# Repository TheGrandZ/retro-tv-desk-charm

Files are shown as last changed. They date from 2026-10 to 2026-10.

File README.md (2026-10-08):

# Retro TV Desk Charm

A tiny 3D printed retro TV that loops short video clips on your desk. You send clips to it straight from your phone over WiFi. No app, no computer, no cables after the first setup.

> **Status:** working prototype. Plays clips, takes uploads from a phone, housing fits.
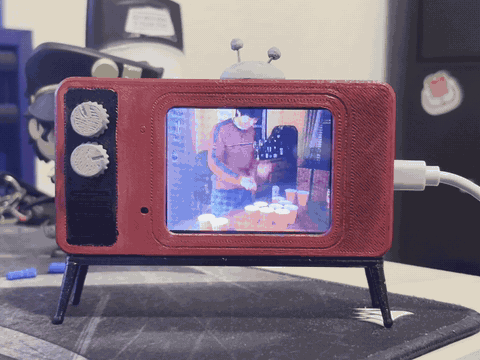
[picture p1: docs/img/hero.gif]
Retro TV playing a clip


## What it does

- **Loops video clips** from a microSD card on a 2.8 inch screen (320 x 240).
- **Phone upload over WiFi.** The TV serves its own web page. Pick a video, choose the start point and length, tap send.
- **Converts in the browser.** The phone turns the video into the format the TV needs, so the TV never has to do heavy work.
- **Clip manager.** Play or delete any clip from the same page.
- **Brightness control** that the TV remembers when unplugged.
- **Turnable magnetic knobs** and a filament-rod antenna, because it is a TV. (Can also use thumbtacks metal)

## Parts

| Part | Notes |
|---|---|
| ESP32-2432S028R ("Cheap Yellow Display") | 2.8 inch ILI9341 touchscreen board. Mine is the two-port version (micro-USB and USB-C). |
| microSD card | Must be **FAT32**. exFAT cards are not read. |
| 4 x disc magnets, 5 x 2 mm | One in each knob, one in each socket. |
| 2 x M3 x 6 mm hex screws | Hold the board in the body. |
| 2 x M3 nuts | Used as spacers under the screw heads. The 6 mm screws were too long for the inserts on their own. |
| M3 brass threaded inserts, about 3 mm long | Set into the body so the screws bite into metal, not plastic. <!-- TODO: confirm exact insert size from the bag --> |
| 1.75 mm filament offcuts | Used as dowel pins and as the antenna rods. |
| USB-C cable | Power only. |
| PLA | Printed on an Ender 3 Pro. |

## How it works

```mermaid
flowchart LR
    A[Phone browser] -->|1. pick video, choose start and length| B[Page draws each frame to a canvas]
    B -->|2. saves frames as JPEGs, 320 x 240| C[One .mjpeg file]
    C -->|3. WiFi upload| D[ESP32 web server]
    D -->|4. writes to| E[(microSD /mjpeg)]
    E -->|5. read frame| F[JPEG decoder]
    F -->|6. draw| G[2.8 inch screen]
```

**MJPEG in one line:** a video stored as a stack of ordinary JPEG pictures, one per frame. It is a bigger file than a normal video, but it is simple enough for a small chip to decode.

### Firmware

- Arduino sketch for the ESP32 (Arduino core 3.x), about 830 lines.
- Starts its own WiFi network (`RetroTV`), or joins home WiFi if the SD card has a `wifi.txt` file. On home WiFi the page is at `http://retrotv.local`.
- Web server routes: `/` (the page), `/list`, `/play`, `/delete`, `/upload`, `/light`.
- **Uploads never interrupt a frame.** A new clip is written to a temp file, then swapped in between clips.
- **Frame skipping.** If the board cannot keep up, it drops frames instead of slowing down, so a 5 second clip still takes 5 seconds.
- **Oversized frames are handled safely.** A frame larger than the buffer stops that clip instead of overflowing memory.
- Clip speed is stored in the file name, for example `beach.f12.mjpeg` plays at 12 frames a second.

### Phone page

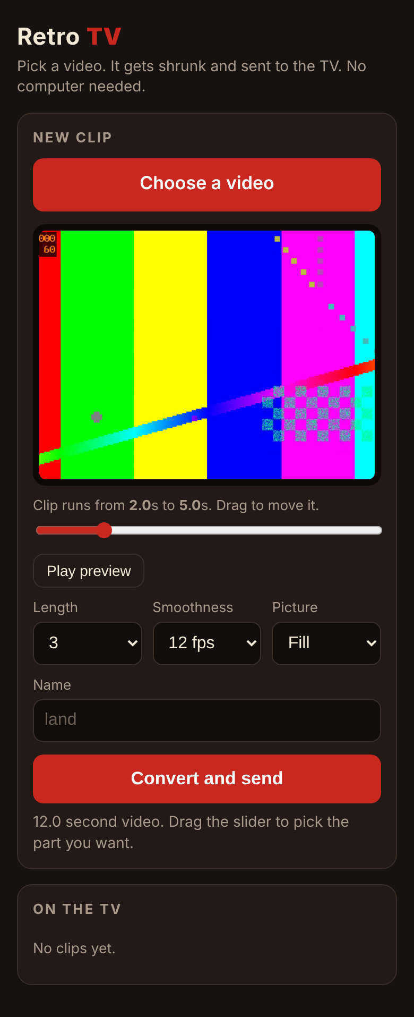
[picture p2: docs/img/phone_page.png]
The upload page on a phone


- One HTML file (about 14 KB) stored inside the firmware.
- Live preview while you drag the start slider, plus a "Play preview" button.
- Fast conversion: plays the video at 2x and grabs frames as they appear (`requestVideoFrameCallback`). Older browsers fall back to a slower frame-by-frame method.
- Frames that come out too big are re-compressed before sending.

### Housing

- Modelled in code (Python with `trimesh` and `manifold3d`), not in a CAD program. Every dimension is a named number in one script, so a fit problem is a one line change and a re-export.
- Built around an existing CYD front case so the board seat was already proven.
- Printed parts: body, stand, 2 knobs, antenna base, 2 antenna tips. <!-- TODO: add the rear cap back to this list if you kept it -->
- **No printed back cover.** The board is screwed straight into the body with M3 brass threaded inserts and hex screws, so it can come out and go back in without wearing out the plastic.
- Small fit-test pieces (USB and SD end, one knob socket) so I could check fit with a short print instead of reprinting the whole body.

## Design log

Eight housing revisions. Each one came from a real print and a real problem.

| Problem found on the print | Fix |
|---|---|
| Shell blocked the USB-C port (I had only opened the micro-USB side) | Opened the USB-C side, then narrowed it to a port-only window |
| Rear cap would not sit flush and warped | Redesigned as a thicker cap with a lip and pegs |
| SD card sat too deep to pull out | Added a finger scoop and a guided slot |
| Unused connectors and bare board visible | Covered them, added a faceplate around USB-C |
| Screen sat too far behind the front (2.6 mm) | Removed an extra lip, now 1.0 mm |
| Knob panel printed as loose strands | A wide recess on the bed side was printing in mid-air. Replaced with a flat panel and a thin outline groove |
| Whole body was exported upside down | Re-exported front face down |
| Printed back cover did not hold tight | Dropped it. M3 brass threaded inserts in the body, board held with M3 hex screws |

**Lessons I would reuse:**

1. **Print a small test piece first.** Most fit bugs showed up on a small test piece, not the full body.
2. **Nothing wide and hollow on the bed-side face.** It has to bridge in mid-air.
3. **Check orientation in the slicer every time.** One wrong flip hid behind several "print quality" problems.

## Performance

Measured on the real board, from the serial log:

| Clip target | What the board managed |
|---|---|
| 15 fps | 11.8 to 11.9 fps |

So the practical ceiling is **about 12 fps at 320 x 240**. The page defaults to 12 fps for that reason, and frame skipping covers the 15 fps option.

Likely bottlenecks, not yet measured separately: reading from the SD card, JPEG decoding, and pushing pixels over SPI. The firmware prints a per-frame timing breakdown to help find out which.

## Testing

- **Phone page:** automated browser tests (Playwright) against a mock TV server. Covers preview scrubbing, landscape and portrait video, fill and fit, name cleaning, oversized frames, and the older-browser path.
- **Firmware logic:** the real sketch compiled on a PC with stand-in hardware headers and the real JPEG decoder, run under AddressSanitizer. 43 checks across four boot scenarios (own network, empty card, home WiFi, home WiFi unreachable). This caught two memory bugs in the original MJPEG reader.
- **Real hardware:** playback and WiFi upload confirmed on the board. The brightness slider is checked in simulation only so far.

Run them yourself:

```bash
tests/page/run_tests.sh   # phone page, needs Python and Playwright
tests/sim/run_sim.sh      # firmware logic, needs g++ and git
```

## Limits

- No sound.
- Up to 40 clips, up to 30 seconds each.
- About 12 fps.
- FAT32 cards only.
- WiFi networks that need a username (like eduroam) do not work.
- The stand's second pin hole misses the frame, so it uses one pin plus glue.

## What I would do next

- Find the real fps bottleneck with the timing report, then try lighter JPEGs or splitting decode and draw across the two CPU cores.
- An ESP32-S3 board for 24 fps and sound.
- Battery and charging in the empty space at the back.
- Fix the stand pin hole.

## What is in this repo

| Folder | What |
|---|---|
| `firmware/RetroTV_Player/` | The Arduino sketch. `webpage.h` is the phone page stored as a string. |
| `firmware/page/` | The phone page source (`index.html`). |
| `case/` | The Python script that builds the housing, and the printable STL files. |
| `tests/` | Browser tests for the page and the PC simulation of the firmware. |
| `docs/img/` | Pictures. |

## Build it

1. **Flash:** open `firmware/RetroTV_Player/RetroTV_Player.ino` in Arduino IDE, board "ESP32 Dev Module", install the libraries *GFX Library for Arduino* and *JPEGDEC*, upload. Set `SCREEN_ROTATION` to 1 or 3 if the picture is upside down.
2. **Card:** format a microSD as FAT32 and insert it.
3. **Print:** body front face down.
4. **Mount the board:** set the M3 brass inserts into the body, then fasten the board with the two M3 x 6 mm hex screws, with an M3 nut on each screw as a spacer.
5. **Send a clip:** join the `RetroTV` WiFi, open `http://192.168.4.1`, choose a video.

Full steps are in `firmware/RetroTV_Player/README.txt`.

## Credits

- Video player based on [esp32-2432S028_video_player](https://github.com/thelastoutpostworkshop/esp32-2432S028_video_player) by thelastoutpostworkshop (MIT license, included).
- Libraries: [Arduino_GFX](https://github.com/moononournation/Arduino_GFX), [JPEGDEC](https://github.com/bitbank2/JPEGDEC).
- The TV body is a remix of [ESP32 2.8inch CYD LCD screen case](https://www.printables.com/model/645166-esp32-28inch-touch-ips-cyd-lcd-screen-case) by jeepers01, licensed [CC BY-SA 4.0](https://creativecommons.org/licenses/by-sa/4.0/). Changes: the original front case is kept as the board seat and a retro TV shell is built around it, with a USB-C opening, SD card scoop, knob sockets and covered-up unused ports. <!-- TODO: confirm this is the page you downloaded from, then delete this note -->
- Built with AI assistance (Claude) for the modelling scripts and firmware. I set the requirements, printed and tested every revision, and decided what to change.

## License

- **Code** (firmware, phone page, scripts, tests): MIT, see `LICENSE`.
- **STL files in `case/stl/`:** [CC BY-SA 4.0](https://creativecommons.org/licenses/by-sa/4.0/), see `case/LICENSE.md`. The body is a remix of a CC BY-SA case, so it has to carry the same license. The other parts use it too so the whole print has one license.

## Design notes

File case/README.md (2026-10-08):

# Case

The housing is built by a Python script, not drawn in a CAD program.

## Print these (`stl/`)

| File | Count | Notes |
|---|---|---|
| `tv_body_v8_no_sensor_hole.stl` | 1 | The body. Print front face down, as saved. |
| `tv_body_v8.stl` | alternative | Same body with a small hole over the board's light sensor. This firmware does not use the sensor, so only pick this one if you plan to add that yourself. |
| `tv_stand_v8.stl` | 1 | |
| `tv_knob_magnetic_x2.stl` | 2 | Takes a 5 x 2 mm magnet. |
| `tv_antenna_base.stl` | 1 | |
| `tv_antenna_tip_x2.stl` | 2 | Rods are 1.75 mm filament offcuts. |
| `tv_rear_cap_v8.stl` | optional | Closes the back. |
| `FIT_TEST_usb_and_sd_end.stl` | optional | Small piece to check USB-C and SD card fit before printing the whole body. |
| `FIT_TEST_knob_socket.stl` | optional | Small piece to check magnet and knob fit. |

The board is held in the body with M3 brass threaded inserts and two M3 x 6 mm hex screws (an M3 nut on each screw as a spacer).

## Rebuild the STL files

1. Download the original CYD front case (link in `LICENSE.md`) and save it as `original/2.8inch_Front_Case.stl`.
2. `pip install trimesh manifold3d numpy`
3. From this folder: `python build_tv.py`

The script writes the body, rear cap, stand, knob and both test pieces into `stl/`. Every dimension is a named number near the top. The antenna parts and the no-hole body come from earlier one-off scripts and are included as STL only.

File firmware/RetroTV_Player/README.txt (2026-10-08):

RetroTV Player  (video player + phone upload over WiFi)
========================================================

INSTALL (one time, needs the computer)
1. Open RetroTV_Player.ino in Arduino IDE (keep all the files in this folder together).
2. Near the top, set SCREEN_ROTATION to the number that worked in your old sketch (1 or 3).
   If you changed anything else in the old sketch to make your screen work, change it here too.
3. Optional: change AP_PASSWORD (at least 8 characters).
4. Board: "ESP32 Dev Module". Click Upload.
   If Arduino says "Sketch too big": Tools > Partition Scheme > "Huge APP (3MB No OTA/1MB SPIFFS)".

SEND A CLIP FROM YOUR PHONE
1. Power the TV. The screen shows a WiFi name and an address for a few seconds.
2. On the phone: join the WiFi "RetroTV" (password: retrotv123).
   The phone may warn "no internet". That is expected. Stay connected.
3. Open the browser and go to   http://192.168.4.1
4. Choose a video, pick the part you want, tap "Convert and send".
   Keep the page open until it says Done. The clip starts playing on the TV.

USE YOUR HOME WIFI INSTEAD (optional)
Put a text file named wifi.txt in the top folder of the SD card:
   line 1: your WiFi name
   line 2: your WiFi password
The TV then joins your WiFi, and the page is at http://retrotv.local
(or the number address the TV shows at power-on). Your phone keeps its internet.
If the TV cannot join, it falls back to making the "RetroTV" network.
School / work WiFi that needs a username (like eduroam) will not work.

BRIGHTNESS
The page has a Brightness slider. The TV remembers it when unplugged.

GOOD TO KNOW
- Clips are saved in the /mjpeg folder, same as before. Old clips still play.
- New clips are named like  beach.f12.mjpeg . The f12 is the speed (12 frames a second).
- Up to 40 clips. Up to 30 seconds per clip. No sound.
- Sending a clip with a name that already exists replaces the old one.

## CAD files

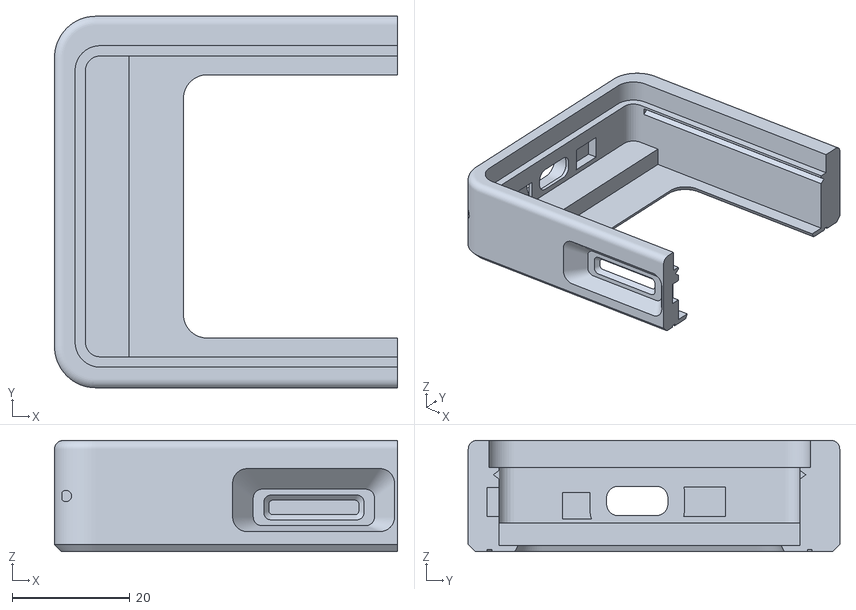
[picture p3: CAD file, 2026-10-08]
case/stl/FIT_TEST_usb_and_sd_end.stl
58.2 x 63.1 x 18.9

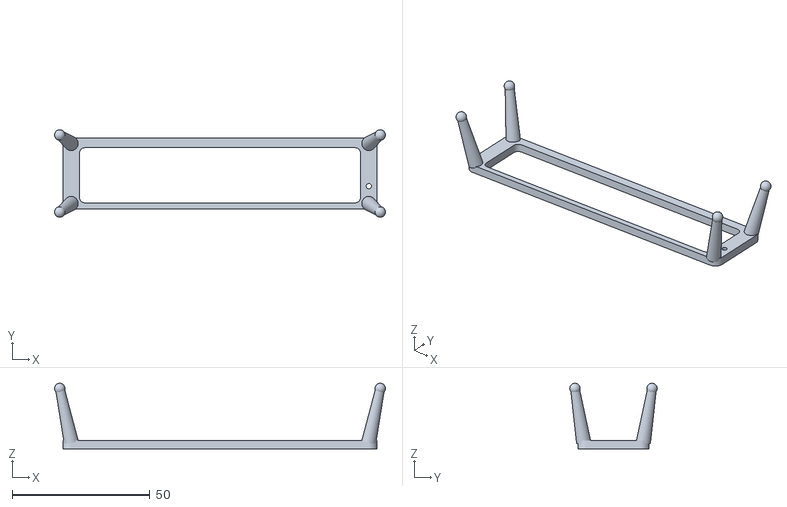
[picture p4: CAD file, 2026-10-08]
case/stl/tv_stand_v8.stl
120.1 x 31.8 x 23.8

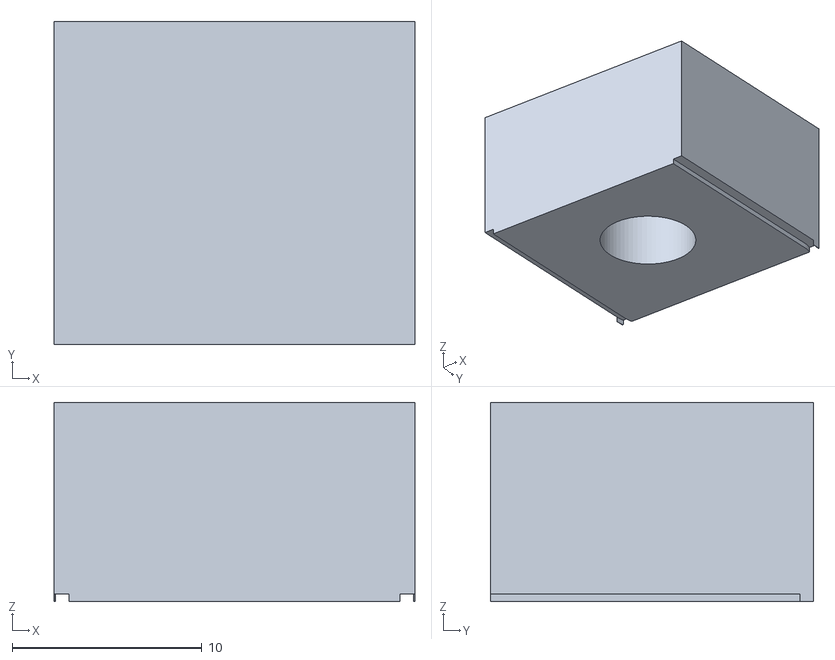
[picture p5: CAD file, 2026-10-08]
case/stl/FIT_TEST_knob_socket.stl
19.0 x 17.0 x 10.5

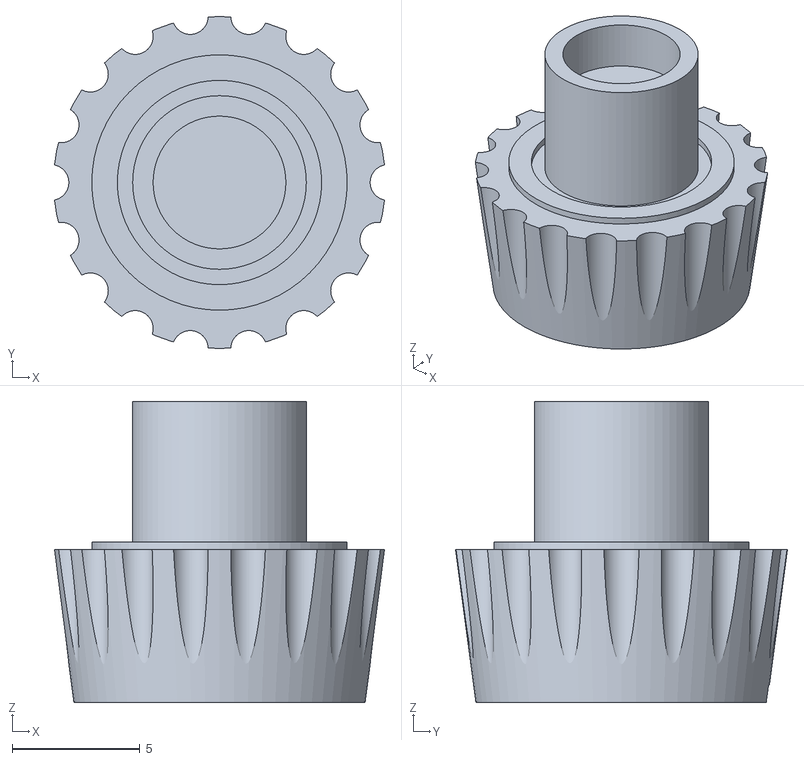
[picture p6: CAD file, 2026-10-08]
case/stl/tv_knob_magnetic_x2.stl
12.9 x 13.0 x 11.8

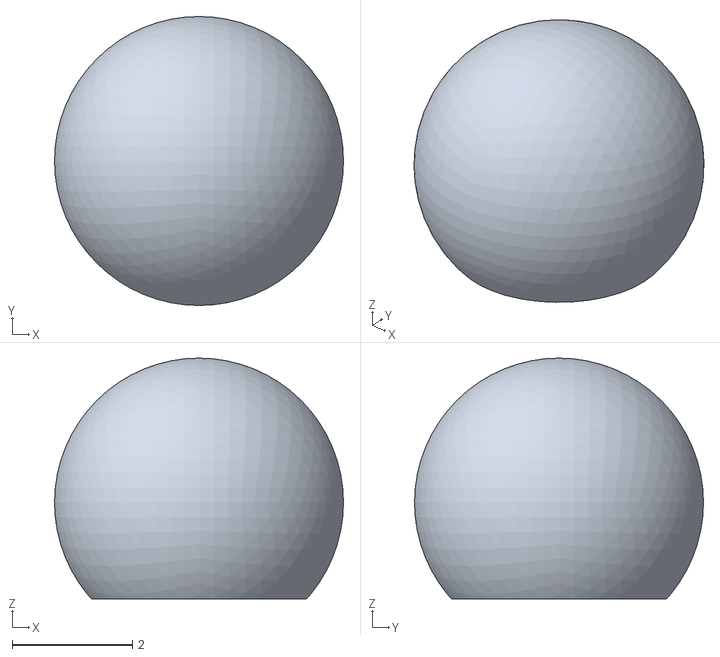
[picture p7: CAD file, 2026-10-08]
case/stl/tv_antenna_tip_x2.stl
4.80 x 4.80 x 4.00

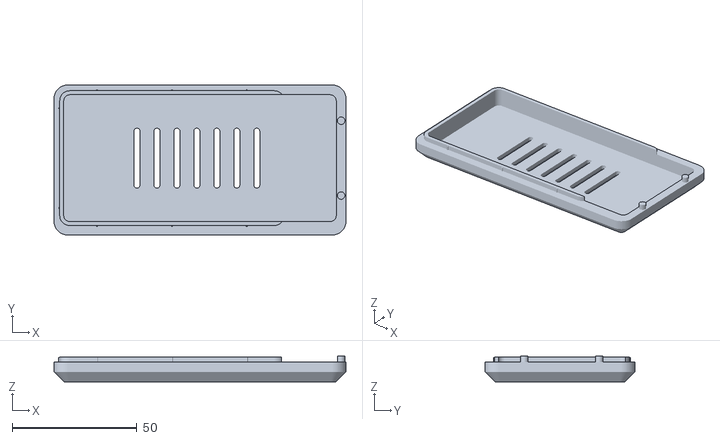
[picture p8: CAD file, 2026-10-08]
case/stl/tv_rear_cap_v8.stl
117.0 x 60.1 x 10.3

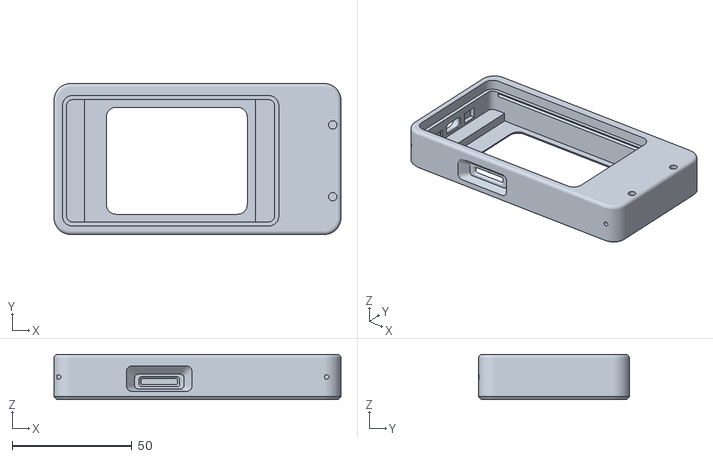
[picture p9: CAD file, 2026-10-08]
case/stl/tv_body_v8_no_sensor_hole.stl
120.0 x 63.1 x 18.9

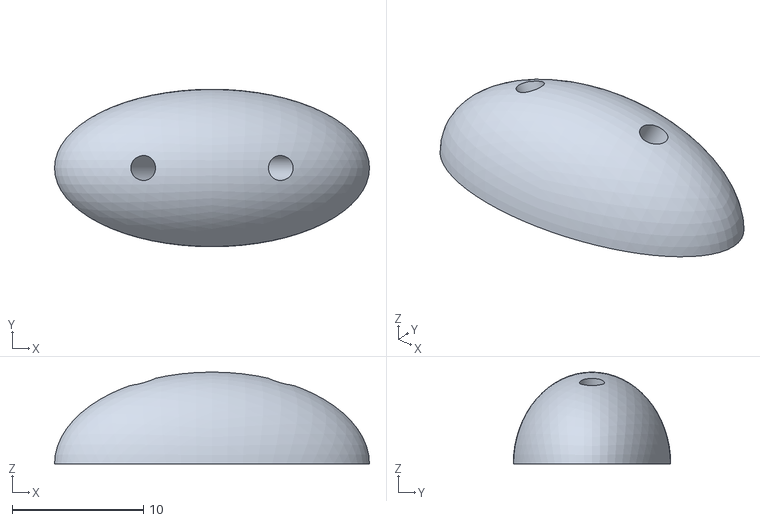
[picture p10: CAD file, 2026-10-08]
case/stl/tv_antenna_base.stl
24.0 x 12.0 x 7.00

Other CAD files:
case/stl/tv_body_v8.stl

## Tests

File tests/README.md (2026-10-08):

# Tests

Neither set needs the real hardware.

## `page/` : the phone page in a real browser

A small fake TV (`mock_tv.py`) serves the page. A headless browser picks a video, drags the slider, converts and uploads.

```bash
pip install playwright && playwright install chromium
./page/run_tests.sh
```

`land.webm` and `port.webm` are generated test patterns (one landscape, one portrait).

## `sim/` : the firmware on a PC

The real `.ino` file is compiled for a PC. The headers in `shim/` stand in for the screen, SD card, WiFi and web server. The JPEG decoder is the real library. Everything runs under AddressSanitizer, which reports memory mistakes.

```bash
./sim/run_sim.sh
```

Expected last line: `checks passed: 43   failed: 0`

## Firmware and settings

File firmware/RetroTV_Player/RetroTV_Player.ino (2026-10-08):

// RetroTV Player
// Plays the .mjpeg clips in the /mjpeg folder of the SD card, and hosts a small web page
// so a phone can convert a video and send it to the SD card over WiFi (no computer needed).
//
// Based on the ESP32-2432S028 video player by The Last Outpost Workshop (MIT License):
// https://github.com/thelastoutpostworkshop/esp32-2432S028_video_player
//
// Board: "ESP32 Dev Module"
// Libraries (Library Manager): "GFX Library for Arduino" and "JPEGDEC"  (same two as before)
// WiFi, WebServer, ESPmDNS and SD come with the ESP32 board package. Nothing new to install.

#include <Arduino_GFX_Library.h>
#include "MjpegClass.h"
#include "webpage.h"
#include "SD.h"
#include <WiFi.h>
#include <WebServer.h>
#include <ESPmDNS.h>
#include <Preferences.h>

// ======================= SETTINGS YOU MIGHT CHANGE =======================
#define SCREEN_ROTATION 1 // 1 or 3 for a sideways (landscape) screen. Use the number that worked in your old sketch.
#define INVERT_DISPLAY false // set to true if the colors look like a photo negative
#define BL_PIN 21            // backlight pin (27 on a few boards)
#define DISPLAY_SPI_SPEED 80000000L // try 40000000L if the picture is glitchy

const char *AP_NAME = "RetroTV";        // WiFi network the TV creates
const char *AP_PASSWORD = "retrotv123"; // at least 8 characters
const char *HOST_NAME = "retrotv";      // on home WiFi the page is http://retrotv.local
#define INFO_SCREEN_MS 6000             // how long the "how to connect" screen shows at power-on
// ==========================================================================

#define SD_CS 5
#define SD_MISO 19
#define SD_MOSI 23
#define SD_SCK 18
#define SD_SPI_SPEED 80000000L

#define SKIP_BUTTON_PIN 0
#define BOOT_BUTTON_DEBOUCE_TIME 400

const char *MJPEG_FOLDER = "/mjpeg";
const char *UPLOAD_TMP = "/mjpeg/incoming.tmp"; // uploads land here first, then get renamed
const char *WIFI_FILE = "/wifi.txt";            // optional: line 1 = WiFi name, line 2 = password

#define MAX_FILES 40
String mjpegFileList[MAX_FILES];
uint32_t mjpegFileSizes[MAX_FILES] = {0};
int mjpegCount = 0;
static int currentMjpegIndex = 0;
String nowPlaying = "";

MjpegClass mjpeg;
int total_frames;        // frames read from the clip (shown + skipped)
int shown_frames;        // frames actually drawn
int skipped_frames;      // frames skipped to keep the clip at the right speed
uint32_t draw_ms;        // time spent pushing pixels to the screen
unsigned long start_ms;
long output_buf_size, estimateBufferSize;
uint8_t *mjpeg_buf;
uint16_t *output_buf;

Arduino_DataBus *bus = new Arduino_HWSPI(2 /* DC */, 15 /* CS */, 14 /* SCK */, 13 /* MOSI */, 12 /* MISO */);
Arduino_GFX *gfx = new Arduino_ILI9341(bus);
SPIClass sd_spi(VSPI);

// ---- web server state ----
WebServer server(80);
String tvAddress = "";   // what to type in the phone's browser
bool onHomeWifi = false; // true = joined your WiFi, false = TV made its own network

// Things the web page asks for are done between clips, never while a file is open.
enum PendingOp
{
    OP_NONE,
    OP_FINISH_UPLOAD,
    OP_DELETE,
    OP_PLAY
};
PendingOp pendingOp = OP_NONE;
String pendingName = "";
bool stopPlayback = false;

File uploadFile;
bool uploadActive = false; // false = this upload is being ignored because the TV was busy
bool uploadOk = false;
String uploadTarget = "";
size_t uploadExpected = 0;
int uploadLastPct = -1;
bool idleScreenShown = false;

volatile bool skipRequested = false;
uint32_t lastPress = 0;

void IRAM_ATTR onButtonPress()
{
    skipRequested = true;
}

// ------------------------------------------------------------------ helpers

bool isMjpegVideoFileName(const String &fileName)
{
    int slashIndex = fileName.lastIndexOf('/');
    String baseName = slashIndex >= 0 ? fileName.substring(slashIndex + 1) : fileName;
    return baseName.endsWith(".mjpeg") && !baseName.startsWith("._");
}

String clipPath(const String &fileName)
{
    return String(MJPEG_FOLDER) + "/" + fileName;
}

// "beach.f12.mjpeg" -> 12.  0 means "no speed tag, play as fast as possible" (old clips).
int fpsFromName(const String &fileName)
{
    if (!fileName.endsWith(".mjpeg"))
        return 0;
    String stem = fileName.substring(0, fileName.length() - 6);
    int p = stem.lastIndexOf(".f");
    if (p < 0)
        return 0;
    String digits = stem.substring(p + 2);
    if (digits.length() == 0 || digits.length() > 2)
        return 0;
    for (unsigned int i = 0; i < digits.length(); i++)
    {
        if (!isDigit(digits[i]))
            return 0;
    }
    int fps = digits.toInt();
    return (fps >= 1 && fps <= 30) ? fps : 0;
}

// "beach.f12.mjpeg" -> "beach"
String clipBaseName(const String &fileName)
{
    String stem = fileName;
    if (stem.endsWith(".mjpeg"))
        stem = stem.substring(0, stem.length() - 6);
    if (fpsFromName(fileName) > 0)
        stem = stem.substring(0, stem.lastIndexOf(".f"));
    return stem;
}

// Keep only letters, numbers, _ and - so a name can never point outside the mjpeg folder.
String cleanName(const String &raw)
{
    String out = "";
    for (unsigned int i = 0; i < raw.length() && out.length() < 20; i++)
    {
        char c = raw[i];
        if (isAlphaNumeric(c) || c == '_' || c == '-')
            out += c;
    }
    if (out.length() == 0)
        out = "clip";
    return out;
}

int indexOfClip(const String &fileName)
{
    for (int i = 0; i < mjpegCount; i++)
    {
        if (mjpegFileList[i] == fileName)
            return i;
    }
    return -1;
}

void loadMjpegFilesList()
{
    mjpegCount = 0;
    File mjpegDir = SD.open(MJPEG_FOLDER);
    if (!mjpegDir || !mjpegDir.isDirectory())
    {
        Serial.printf("No %s folder\n", MJPEG_FOLDER);
        return;
    }
    while (true)
    {
        File file = mjpegDir.openNextFile();
        if (!file)
            break;
        if (!file.isDirectory())
        {
            String name = file.name();
            int slash = name.lastIndexOf('/');
            if (slash >= 0)
                name = name.substring(slash + 1);
            if (isMjpegVideoFileName(name) && mjpegCount < MAX_FILES)
            {
                mjpegFileList[mjpegCount] = name;
                mjpegFileSizes[mjpegCount] = file.size();
                mjpegCount++;
            }
        }
        file.close();
    }
    mjpegDir.close();
    Serial.printf("%d mjpeg files found\n", mjpegCount);
}

// ------------------------------------------------------------------ screens

void textLine(int16_t y, uint8_t size, uint16_t color, const String &text)
{
    gfx->setTextSize(size);
    gfx->setTextColor(color);
    gfx->setCursor(10, y);
    gfx->print(text);
}

void showInfoScreen(const char *title)
{
    gfx->fillScreen(RGB565_BLACK);
    textLine(12, 3, RGB565_RED, title);
    if (onHomeWifi)
    {
        textLine(60, 2, RGB565_WHITE, "On your phone, open:");
        textLine(90, 2, RGB565_YELLOW, String("http://") + HOST_NAME + ".local");
        textLine(120, 2, RGB565_WHITE, "or");
        textLine(150, 2, RGB565_YELLOW, "http://" + tvAddress);
    }
    else
    {
        textLine(60, 2, RGB565_WHITE, "1. Join this WiFi:");
        textLine(86, 2, RGB565_YELLOW, String("   ") + AP_NAME);
        textLine(112, 2, RGB565_WHITE, String("   pass: ") + AP_PASSWORD);
        textLine(150, 2, RGB565_WHITE, "2. In the browser open:");
        textLine(176, 2, RGB565_YELLOW, "   http://" + tvAddress);
    }
}

void showReceiving(int pct)
{
    if (pct == uploadLastPct)
        return;
    if (uploadLastPct < 0)
    {
        gfx->fillRect(20, 80, gfx->width() - 40, 80, RGB565_BLACK);
        gfx->drawRect(20, 80, gfx->width() - 40, 80, RGB565_WHITE);
        textLine(92, 2, RGB565_WHITE, "   Receiving clip...");
        gfx->drawRect(40, 124, gfx->width() - 80, 18, RGB565_WHITE);
    }
    uploadLastPct = pct;
    int w = (gfx->width() - 84) * constrain(pct, 0, 100) / 100;
    gfx->fillRect(42, 126, w, 14, RGB565_RED);
}

// ------------------------------------------------------------------ web page handlers

void handleRoot()
{
    server.send_P(200, "text/html", INDEX_HTML);
}

String jsonEscape(const String &s)
{
    String out = "";
    for (unsigned int i = 0; i < s.length(); i++)
    {
        char c = s[i];
        if (c == '"' || c == '\\')
            out += '\\';
        if ((uint8_t)c >= 32)
            out += c;
    }
    return out;
}

void handleList()
{
    String json = "{\"clips\":[";
    for (int i = 0; i < mjpegCount; i++)
    {
        if (i)
            json += ",";
        json += "{\"n\":\"" + jsonEscape(mjpegFileList[i]) + "\",\"s\":" + String(mjpegFileSizes[i]) + "}";
    }
    json += "],\"now\":\"" + jsonEscape(nowPlaying) + "\"}";
    server.sendHeader("Cache-Control", "no-store");
    server.send(200, "application/json", json);
}

// Shared by /play and /delete: the clip must be one we listed ourselves.
void queueClipOp(PendingOp op)
{
    String name = server.arg("name");
    if (pendingOp != OP_NONE)
    {
        server.send(409, "text/plain", "The TV is busy. Try again in a second.");
        return;
    }
    if (indexOfClip(name) < 0)
    {
        server.send(404, "text/plain", "That clip is not on the TV any more.");
        return;
    }
    pendingName = name;
    pendingOp = op;
    stopPlayback = true;
    server.send(200, "text/plain", "OK");
}

void handlePlay()
{
    queueClipOp(OP_PLAY);
}

void handleDelete()
{
    queueClipOp(OP_DELETE);
}

// Called many times while the phone is sending a clip.
void handleUploadData()
{
    HTTPUpload &up = server.upload();
    if (up.status == UPLOAD_FILE_START)
    {
        uploadOk = false;
        uploadLastPct = -1;
        uploadActive = (pendingOp == OP_NONE);
        if (!uploadActive)
            return; // still finishing the previous request: ignore this one, the phone gets an error
        int fps = constrain((int)server.arg("fps").toInt(), 0, 30);
        uploadTarget = cleanName(server.arg("name")) + (fps > 0 ? ".f" + String(fps) : String("")) + ".mjpeg";
        uploadExpected = (size_t)server.arg("size").toInt();
        if (!SD.exists(MJPEG_FOLDER))
            SD.mkdir(MJPEG_FOLDER);
        SD.remove(UPLOAD_TMP);
        uploadFile = SD.open(UPLOAD_TMP, FILE_WRITE);
        uploadOk = (bool)uploadFile;
        Serial.printf("Upload start: %s (%u bytes expected)\n", uploadTarget.c_str(), (unsigned)uploadExpected);
        showReceiving(0);
    }
    else if (!uploadActive)
    {
        return;
    }
    else if (up.status == UPLOAD_FILE_WRITE)
    {
        if (uploadOk && uploadFile.write(up.buf, up.currentSize) != up.currentSize)
        {
            uploadOk = false; // SD card full or pulled out
        }
        if (uploadExpected > 0)
            showReceiving((int)(100.0 * up.totalSize / uploadExpected));
    }
    else if (up.status == UPLOAD_FILE_END)
    {
        if (uploadFile)
            uploadFile.close();
        if (uploadOk && up.totalSize > 0 && (uploadExpected == 0 || up.totalSize == uploadExpected))
        {
            pendingName = uploadTarget;
            pendingOp = OP_FINISH_UPLOAD;
            stopPlayback = true;
            Serial.printf("Upload done: %u bytes\n", (unsigned)up.totalSize);
        }
        else
        {
            uploadOk = false;
            SD.remove(UPLOAD_TMP);
            stopPlayback = true; // restart the clip so the "Receiving" box is cleared
            idleScreenShown = false;
            Serial.println("Upload failed");
        }
    }
    else if (up.status == UPLOAD_FILE_ABORTED)
    {
        if (uploadFile)
            uploadFile.close();
        SD.remove(UPLOAD_TMP);
        uploadOk = false;
        stopPlayback = true; // restart the clip so the "Receiving" box is cleared
        idleScreenShown = false;
        Serial.println("Upload aborted");
    }
}

// Called once when the upload request is complete.
void handleUploadDone()
{
    if (uploadOk)
        server.send(200, "text/plain", "OK");
    else if (!uploadActive)
        server.send(409, "text/plain", "The TV is busy. Try again in a second.");
    else
        server.send(500, "text/plain", "The TV could not save the clip. The SD card may be full or missing.");
}

// ------------------------------------------------------------------ brightness

Preferences prefs;    // remembers the brightness when the TV is unplugged
int lightLevel = 255; // brightness set from the phone page (10..255)
float blNow = 255;    // brightness the backlight is at right now
int blWritten = -1;
uint32_t lightTick = 0;

// Called very often; does its work about ten times a second. Fades instead of jumping.
void updateBacklight()
{
    uint32_t now = millis();
    if (now - lightTick < 100)
        return;
    lightTick = now;
    float step = constrain((float)lightLevel - blNow, -6.0f, 6.0f);
    blNow += step;
    int out = constrain((int)(blNow + 0.5f), 10, 255);
    if (out != blWritten)
    {
        analogWrite(BL_PIN, out);
        blWritten = out;
    }
}

void loadLightSettings()
{
    prefs.begin("retrotv", false);
    lightLevel = constrain(prefs.getInt("level", 255), 10, 255);
    blNow = lightLevel;
}

// /light            -> current brightness
// /light?level=180  -> change it (10..255)
void handleLight()
{
    if (server.hasArg("level"))
    {
        lightLevel = constrain((int)server.arg("level").toInt(), 10, 255);
        prefs.putInt("level", lightLevel);
    }
    String json = "{\"level\":" + String(lightLevel) + ",\"now\":" + String(blWritten) + "}";
    server.sendHeader("Cache-Control", "no-store");
    server.send(200, "application/json", json);
}

void handleNotFound()
{
    server.send(404, "text/plain", "Not found");
}

// Runs between clips, when no clip file is open.
void runPendingOp()
{
    PendingOp op = pendingOp;
    String name = pendingName;

    if (op == OP_FINISH_UPLOAD)
    {
        // Remove any older clip with the same name (even if it had a different speed tag).
        String base = clipBaseName(name);
        for (int i = 0; i < mjpegCount; i++)
        {
            if (clipBaseName(mjpegFileList[i]) == base)
                SD.remove(clipPath(mjpegFileList[i]));
        }
        if (!SD.rename(UPLOAD_TMP, clipPath(name).c_str()))
            Serial.println("Rename of uploaded clip failed");
        loadMjpegFilesList();
        int idx = indexOfClip(name);
        currentMjpegIndex = idx >= 0 ? idx : 0;
    }
    else if (op == OP_DELETE)
    {
        SD.remove(clipPath(name));
        loadMjpegFilesList();
        if (currentMjpegIndex >= mjpegCount)
            currentMjpegIndex = 0;
    }
    else if (op == OP_PLAY)
    {
        int idx = indexOfClip(name);
        if (idx >= 0)
            currentMjpegIndex = idx;
    }

    pendingOp = OP_NONE;
    pendingName = "";
    stopPlayback = false;
    idleScreenShown = false;
}

// ------------------------------------------------------------------ WiFi

bool readWifiFile(String &ssid, String &pass)
{
    File f = SD.open(WIFI_FILE);
    if (!f || f.isDirectory())
        return false;
    ssid = f.readStringUntil('\n');
    pass = f.readStringUntil('\n');
    f.close();
    ssid.trim();
    pass.trim();
    return ssid.length() > 0;
}

void startWifi()
{
    String ssid, pass;
    if (readWifiFile(ssid, pass))
    {
        gfx->fillScreen(RGB565_BLACK);
        textLine(12, 3, RGB565_RED, "Retro TV");
        textLine(60, 2, RGB565_WHITE, "Joining WiFi:");
        textLine(86, 2, RGB565_YELLOW, ssid);
        WiFi.mode(WIFI_STA);
        WiFi.setHostname(HOST_NAME);
        WiFi.begin(ssid.c_str(), pass.c_str());
        uint32_t t0 = millis();
        while (WiFi.status() != WL_CONNECTED && millis() - t0 < 15000)
        {
            delay(250);
        }
        if (WiFi.status() == WL_CONNECTED)
        {
            onHomeWifi = true;
            tvAddress = WiFi.localIP().toString();
            WiFi.setSleep(false); // faster uploads
            if (MDNS.begin(HOST_NAME))
                MDNS.addService("http", "tcp", 80);
            Serial.printf("Joined %s, address %s\n", ssid.c_str(), tvAddress.c_str());
            return;
        }
        Serial.println("Could not join the WiFi in wifi.txt, making my own network instead");
        WiFi.disconnect(true);
        delay(200);
    }
    WiFi.mode(WIFI_AP);
    WiFi.softAP(AP_NAME, AP_PASSWORD);
    delay(200);
    onHomeWifi = false;
    tvAddress = WiFi.softAPIP().toString();
    Serial.printf("Created WiFi network %s, address %s\n", AP_NAME, tvAddress.c_str());
}

// Wait while still answering the phone.
void serveFor(uint32_t ms)
{
    uint32_t t0 = millis();
    while (millis() - t0 < ms && pendingOp == OP_NONE)
    {
        server.handleClient();
        updateBacklight();
        delay(2);
    }
}

// ------------------------------------------------------------------ setup / loop
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
void loop()
{
    // Finish whatever the phone asked for BEFORE listening for the next request,
    // so two requests can never overlap.
    if (pendingOp != OP_NONE)
        runPendingOp();
    stopPlayback = false;
    server.handleClient();
    updateBacklight();
    if (pendingOp != OP_NONE)
        runPendingOp();
    stopPlayback = false;

    if (mjpegCount == 0)
    {
        nowPlaying = "";
        if (!idleScreenShown)
        {
            showInfoScreen("No clips yet");
            idleScreenShown = true;
        }
        delay(5);
        return;
    }

    if (currentMjpegIndex >= mjpegCount)
        currentMjpegIndex = 0;
    playClip(mjpegFileList[currentMjpegIndex]);

    // Finished on its own (or skipped with the button): go to the next clip.
    // Stopped by the phone: runPendingOp() decides what plays next.
    // Stopped by a failed upload: play the same clip again.
    if (pendingOp == OP_NONE && !stopPlayback)
        currentMjpegIndex++;
}

// ------------------------------------------------------------------ playback

int jpegDrawCallback(JPEGDRAW *pDraw)
{
    uint32_t t = millis();
    gfx->draw16bitBeRGBBitmap(pDraw->x, pDraw->y, pDraw->pPixels, pDraw->iWidth, pDraw->iHeight);
    draw_ms += millis() - t;
    return 1;
}

void playClip(const String &fileName)
{
    String path = clipPath(fileName);
    Serial.printf("Playing %s\n", path.c_str());
    File mjpegFile = SD.open(path.c_str(), "r");
    if (!mjpegFile || mjpegFile.isDirectory())
    {
        Serial.printf("ERROR: could not open %s\n", path.c_str());
        serveFor(500); // do not spin if the card was pulled
        return;
    }

    nowPlaying = fileName;
    gfx->fillScreen(RGB565_BLACK);
    start_ms = millis();
    total_frames = 0;
    shown_frames = 0;
    skipped_frames = 0;
    draw_ms = 0;
    uint32_t read_ms = 0, decode_and_draw_ms = 0;
    int skipRun = 0;

    int fps = fpsFromName(fileName);
    uint32_t frameMs = fps > 0 ? 1000 / fps : 0; // 0 = as fast as possible
    uint32_t nextFrameAt = millis();             // when the next frame is supposed to appear

    mjpeg.setup(&mjpegFile, mjpeg_buf, jpegDrawCallback, true /* useBigEndian */,
                0, 0, gfx->width(), gfx->height(), estimateBufferSize);

    while (!skipRequested && !stopPlayback && mjpegFile.available())
    {
        uint32_t t0 = millis();
        if (!mjpeg.readMjpegBuf())
            break;
        uint32_t t1 = millis();
        read_ms += t1 - t0;
        total_frames++;

        int32_t late = frameMs > 0 ? (int32_t)(t1 - nextFrameAt) : 0;
        if (late > 500)
        {
            nextFrameAt = t1; // a long pause (an upload): carry on from here instead of racing to catch up
            late = 0;
        }
        if (frameMs > 0 && late > (int32_t)frameMs && skipRun < 3)
        {
            // The board is more than a whole frame behind: do not draw this one, so the clip
            // keeps its real speed instead of turning into slow motion. Never more than 3 in a row.
            skipped_frames++;
            skipRun++;
        }
        else
        {
            mjpeg.drawJpg();
            decode_and_draw_ms += millis() - t1;
            shown_frames++;
            skipRun = 0;
        }

        server.handleClient(); // an upload is handled in here; the clip simply pauses meanwhile
        updateBacklight();

        if (frameMs > 0)
        {
            nextFrameAt += frameMs;
            while (!stopPlayback && (int32_t)(nextFrameAt - millis()) > 0)
            {
                server.handleClient();
                updateBacklight();
                delay(1);
            }
        }
    }

    if (mjpeg.frameTooBig())
        Serial.println("Stopped: this clip has a frame too big for the board's memory.");

    if (skipRequested)
    {
        uint32_t now = millis();
        if (now - lastPress >= BOOT_BUTTON_DEBOUCE_TIME)
            lastPress = now;
    }
    skipRequested = false;

    int time_used = millis() - start_ms;
    mjpegFile.close();
    if (time_used > 0 && shown_frames > 0)
    {
        // "shown per second" is what you actually see. If "skipped" is not 0, the board could not keep up with the target.
        Serial.printf("%d frames in %d ms (target %d fps): shown %d = %0.1f per second, skipped %d\n",
                      total_frames, time_used, fps, shown_frames, 1000.0 * shown_frames / time_used, skipped_frames);
        Serial.printf("   per shown frame: read %0.1f ms, decode %0.1f ms, draw %0.1f ms\n",
                      (float)read_ms / total_frames,
                      (float)(decode_and_draw_ms - draw_ms) / shown_frames,
                      (float)draw_ms / shown_frames);
    }

    if (total_frames == 0)
        serveFor(300); // an empty or broken clip: do not spin
}

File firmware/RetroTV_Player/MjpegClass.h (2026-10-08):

/*******************************************************************************
 * JPEGDEC Wrapper Class
 * From https://github.com/thelastoutpostworkshop/esp32-2432S028_video_player (MIT License)
 * RetroTV changes: optional buffer-size check so an oversized frame cannot crash the board.
 *
 * Dependent libraries:
 * JPEGDEC: https://github.com/bitbank2/JPEGDEC.git
 ******************************************************************************/
#ifndef _MJPEGCLASS_H_
#define _MJPEGCLASS_H_

#define READ_BUFFER_SIZE 1024
#define MAXOUTPUTSIZE (MAX_BUFFERED_PIXELS / 16 / 16)

/* Wio Terminal */
#if defined(ARDUINO_ARCH_SAMD) && defined(SEEED_GROVE_UI_WIRELESS)
#include <Seeed_FS.h>
#elif defined(ESP32) || defined(ESP8266)
#include <FS.h>
#else
#include <SD.h>
#endif

#include <JPEGDEC.h>

class MjpegClass
{
public:
  int getWidth() const { return _jpgWidth; }   
  int getHeight() const { return _jpgHeight; } 
  int getScale() const { return _scale; }      // 0, 1⁄2, 1⁄4, 1⁄8  (JPEG_SCALE_x)
  bool frameTooBig() const { return _too_big; } // RetroTV change: true if a clip was stopped by an oversized frame

  bool setup(
      Stream *input, uint8_t *mjpeg_buf, JPEG_DRAW_CALLBACK *pfnDraw, bool useBigEndian,
      int x, int y, int widthLimit, int heightLimit, int32_t mjpeg_buf_size = 0)
  {
    _mjpeg_buf_size = mjpeg_buf_size; // RetroTV change: 0 = no size check (original behaviour)
    _too_big = false;
    _scale = -1; // RetroTV change: work out the scale again for every clip, so clips of different sizes can be mixed
    _input = input;
    _mjpeg_buf = mjpeg_buf;
    _pfnDraw = pfnDraw;
    _useBigEndian = useBigEndian;
    _x = x;
    _y = y;
    _widthLimit = widthLimit;
    _heightLimit = heightLimit;
    _inputindex = 0;

    if (!_read_buf)
    {
      _read_buf = (uint8_t *)malloc(READ_BUFFER_SIZE + 2); // RetroTV change: +2 because the marker search peeks one byte past the end
    }

    if (!_read_buf)
    {
      return false;
    }

    return true;
  }

  bool readMjpegBuf()
  {
    if (_inputindex == 0)
    {
      _buf_read = _input->readBytes(_read_buf, READ_BUFFER_SIZE);
      _inputindex += _buf_read;
    }
    _mjpeg_buf_offset = 0;
    int i = 0;
    bool found_FFD8 = false;
    while ((_buf_read > 0) && (!found_FFD8))
    {
      i = 0;
      while ((i < _buf_read) && (!found_FFD8))
      {
        if ((_read_buf[i] == 0xFF) && (_read_buf[i + 1] == 0xD8)) // JPEG header
        {
          // Serial.printf("Found FFD8 at: %d.\n", i);
          found_FFD8 = true;
        }
        ++i;
      }
      if (found_FFD8)
      {
        --i;
      }
      else
      {
        _buf_read = _input->readBytes(_read_buf, READ_BUFFER_SIZE);
      }
    }
    uint8_t *_p = _read_buf + i;
    _buf_read -= i;
    bool found_FFD9 = false;
    if (_buf_read > 0)
    {
      i = 3;
      while ((_buf_read > 0) && (!found_FFD9))
      {
        if ((_mjpeg_buf_offset > 0) && (_mjpeg_buf[_mjpeg_buf_offset - 1] == 0xFF) && (_p[0] == 0xD9)) // JPEG trailer
        {
          // Serial.printf("Found FFD9 at: %d.\n", i);
          found_FFD9 = true;
        }
        else
        {
          while ((i < _buf_read) && (!found_FFD9))
          {
            if ((_p[i] == 0xFF) && (_p[i + 1] == 0xD9)) // JPEG trailer
            {
              found_FFD9 = true;
              ++i;
            }
            ++i;
          }
        }

        // Serial.printf("i: %d\n", i);
        if (_mjpeg_buf_size > 0 && _mjpeg_buf_offset + i > _mjpeg_buf_size)
        {
          // RetroTV change: a frame bigger than the buffer used to overflow memory and crash.
          // Stop this clip cleanly instead.
          _too_big = true;
          return false;
        }
        memcpy(_mjpeg_buf + _mjpeg_buf_offset, _p, i);
        _mjpeg_buf_offset += i;
        size_t o = _buf_read - i;
        if (o > 0)
        {
          // Serial.printf("o: %d\n", o);
          memmove(_read_buf, _p + i, o); // RetroTV change: the two ranges overlap, so memmove (was memcpy)
          _buf_read = _input->readBytes(_read_buf + o, READ_BUFFER_SIZE - o);
          _p = _read_buf;
          _inputindex += _buf_read;
          _buf_read += o;
          // Serial.printf("_buf_read: %d\n", _buf_read);
        }
        else
        {
          _buf_read = _input->readBytes(_read_buf, READ_BUFFER_SIZE);
          _p = _read_buf;
          _inputindex += _buf_read;
        }
        i = 0;
      }
      if (found_FFD9)
      {
        return true;
      }
    }

    return false;
  }

  bool drawJpg()
  {
    _remain = _mjpeg_buf_offset;
    _jpeg.openRAM(_mjpeg_buf, _remain, _pfnDraw);
    if (_scale == -1)
    {
      // scale to fit height
      int iMaxMCUs;
      _jpgWidth = _jpeg.getWidth();
      _jpgHeight = _jpeg.getHeight();
      float ratio = (float)_jpgHeight / _heightLimit;
      if (ratio <= 1)
      {
        _scale = 0;
        iMaxMCUs = _widthLimit / 16;
      }
      else if (ratio <= 2)
      {
        _scale = JPEG_SCALE_HALF;
        iMaxMCUs = _widthLimit / 8;
        _jpgWidth /= 2;
        _jpgHeight /= 2;
      }
      else if (ratio <= 4)
      {
        _scale = JPEG_SCALE_QUARTER;
        iMaxMCUs = _widthLimit / 4;
        _jpgWidth /= 4;
        _jpgHeight /= 4;
      }
      else
      {
        _scale = JPEG_SCALE_EIGHTH;
        iMaxMCUs = _widthLimit / 2;
        _jpgWidth /= 8;
        _jpgHeight /= 8;
      }
      _jpeg.setMaxOutputSize(iMaxMCUs);
      _x = (_jpgWidth > _widthLimit) ? 0 : ((_widthLimit - _jpgWidth) / 2);
      _y = (_heightLimit - _jpgHeight) / 2;
    }
    if (_useBigEndian)
    {
      _jpeg.setPixelType(RGB565_BIG_ENDIAN);
    }
    // center the image on the display
    int iXOff, iYOff;
    iXOff = (_widthLimit - _jpeg.getWidth()) / 2;
    if (iXOff < 0)
      iXOff = 0;
    iYOff = (_heightLimit - _jpeg.getHeight()) / 2;
    if (iYOff < 0)
      iYOff = 0;

    _jpeg.decode(iXOff, iYOff, _scale);
    _jpeg.close();

    return true;
  }

private:
  Stream *_input;
  uint8_t *_mjpeg_buf;
  JPEG_DRAW_CALLBACK *_pfnDraw;
  bool _useBigEndian;
  int _x;
  int _y;
  int _widthLimit;
  int _heightLimit;
  int _jpgWidth;
  int _jpgHeight;

  uint8_t *_read_buf = nullptr;
  int32_t _mjpeg_buf_offset = 0;
  int32_t _mjpeg_buf_size = 0;
  bool _too_big = false;

  JPEGDEC _jpeg;
  int _scale = -1;

  int32_t _inputindex = 0;
  int32_t _buf_read;
  int32_t _remain = 0;
};

#endif // _MJPEGCLASS_H_

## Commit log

2026-10-08 Initial commit: firmware, phone page, case, tests
    [FIT_TEST_knob_socket.stl, FIT_TEST_usb_and_sd_end.stl, tv_antenna_base.stl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]
2026-10-08 Update README with thumbtack usage for knobs
    Added a note about using thumbtacks with the magnetic knobs.
